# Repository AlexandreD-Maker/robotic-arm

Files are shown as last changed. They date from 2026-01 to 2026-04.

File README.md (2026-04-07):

# Robotic arm project

This repository contains the complete development of my custom robotic arm project, covering mechanical design, embedded control, and system-level integration.

It includes:

- Arduino code
- CAD designs
- Electrical schematic
- [Documentation](docs/index.md) (Github Pages)
---

## Design evolution
This project started as a manually controlled 4-DOF robotic arm using potentiometers, and was progressively extended toward a more structured and testable control architecture.

The evolution focuses on improving motion reproducibility, control clarity, and system testability.

---

## Global architecture

The robotic arm can be controlled using two control modes:
- **Manual mode:** Direct joint control using potentiometers
- **Code-controlled mode:** Joint position commands are sent via the serial interface, allowing reproducible and testable movements. A feedback LED indicates when this mode is active.

The system starts in manual mode by default.

A push button allows safe switching between control modes.

---

## 🚧 Project status

This project is currently under development.

Ongoing work includes:
- CAD design and assembly validation
- creation and expansion of the [technical documentation](docs/index.md).

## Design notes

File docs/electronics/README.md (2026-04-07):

# Electronics

This folder contains the electronic design of the robotic arm, including the schematic, power architecture, and design rationale behind key technical decisions.

---
## System Overview

The electronic system is responsible for:
- Reading user inputs through potentiometers
- Generating PWM signals for servo motor control
- Distributing power safely between logic and actuators
- Ensuring stable electrical references across the system

The architecture separates logic power and actuator power to improve reliability.

---
## Main Components

- **Microcontroller**  
  Arduino UNO R3 board used for:
  - Analog input acquisition
  - PWM signal generation
  - High-level control logic

- **Actuators**
  - 3 × MG996R servo motors (base, shoulder, elbow)
  - 2 × SG90 servo motors (wrist, gripper)

- **User Inputs**
  - Potentiometers connected to analog inputs

- **Power Supply**
  - External 5V / 4A DC supply dedicated to servos
  - USB power for the microcontroller

---
## Power Architecture and Design Rationale

Servo motors are powered by an external 5V supply to avoid voltage drops, noise injection, and brownouts on the microcontroller power rail.

The power supply was dimensioned based on:
- Typical current consumption of each servo during motion
- Realistic operating scenarios where not all servos are simultaneously stalled
- An additional safety margin suitable for a prototype system

This approach provides sufficient current capacity for normal operation while keeping the system simple and easy to scale.

All grounds (external power supply and microcontroller ground) are tied together to ensure correct signal referencing for PWM and analog inputs.

---
## Analog Input Strategy

Potentiometers are powered from the microcontroller 5V rail and connected to analog input pins.

This ensures:
- A stable reference voltage
- Consistent readings independent of servo power fluctuations
- Signal integrity

---
## Schematic

An overview of the circuit diagram is shown below:

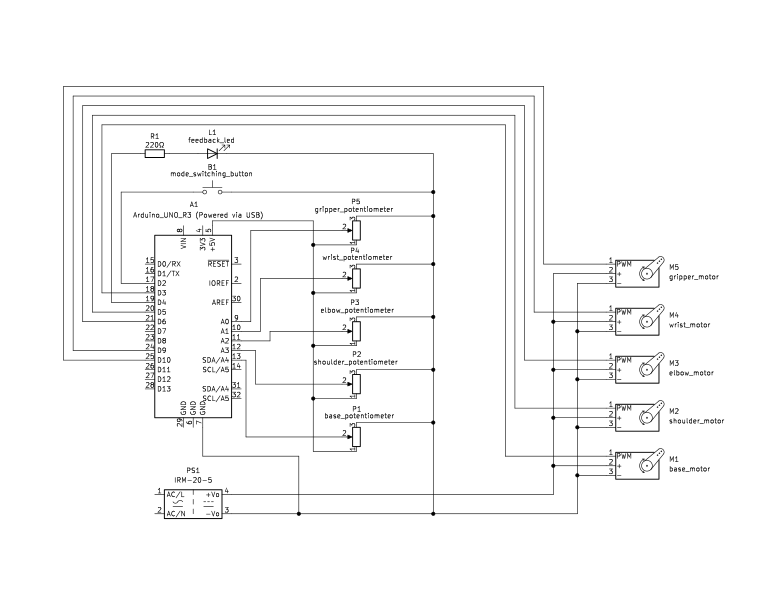
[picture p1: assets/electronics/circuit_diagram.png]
Circuit diagram overview


The complete schematic is also available as a PDF in this directory for detailed inspection.

---
## Tools

- **Schematic design**: KiCad 9.0.6

[Main page](../index.md)

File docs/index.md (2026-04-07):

# Robotic Arm - Technical Documentation

Welcome to the documentation for my custom robotic arm project.

The goal is to design and build a functional and stable robotic arm by using 3D printing, servo motors, potentiometers and an Arduino.
---

## 🎯 Project Goals

- Build a 40 cm robotic arm with clean and stable movements

- Design custom mechanical parts

- Control multiple servos using potentiometers and an Arduino

- Ensure smooth motion without shaking

- Document the project and share all design files
---

## 📂 Repository Structure

- **CAD/** - 3D models (STEP, STL, drawings)
- **electronics/** Circuit diagram
- **firmware/** Control code
- **docs/** Documentation
- **assets/** Images and videos
---

## 🔧 Technologies Used

- **Arduino UNO R3**
- **MG996R / SG90 servos** (depending on the joint)
- **B10K potentiometers** (x5 one for each servos)
- **3D printing** (PLA)
- **Github Pages** for documentation
---

## 📄 Documentation

- **[Electronics](/docs/electronics/README.md)**
- **[Firmware](/firmware/)** (each source file has a doxygen documentation)

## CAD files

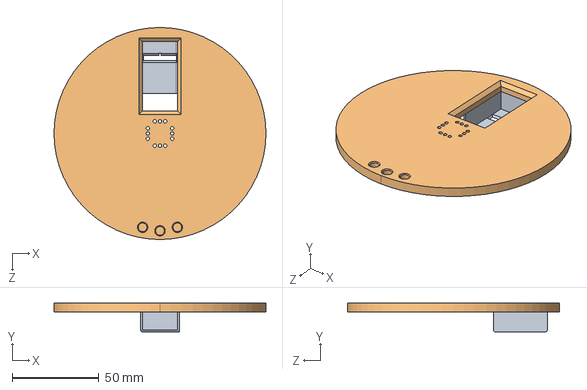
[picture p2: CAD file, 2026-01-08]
CAD/STEP/base_plate.STEP
122.0 x 16.5 x 122.0 mm

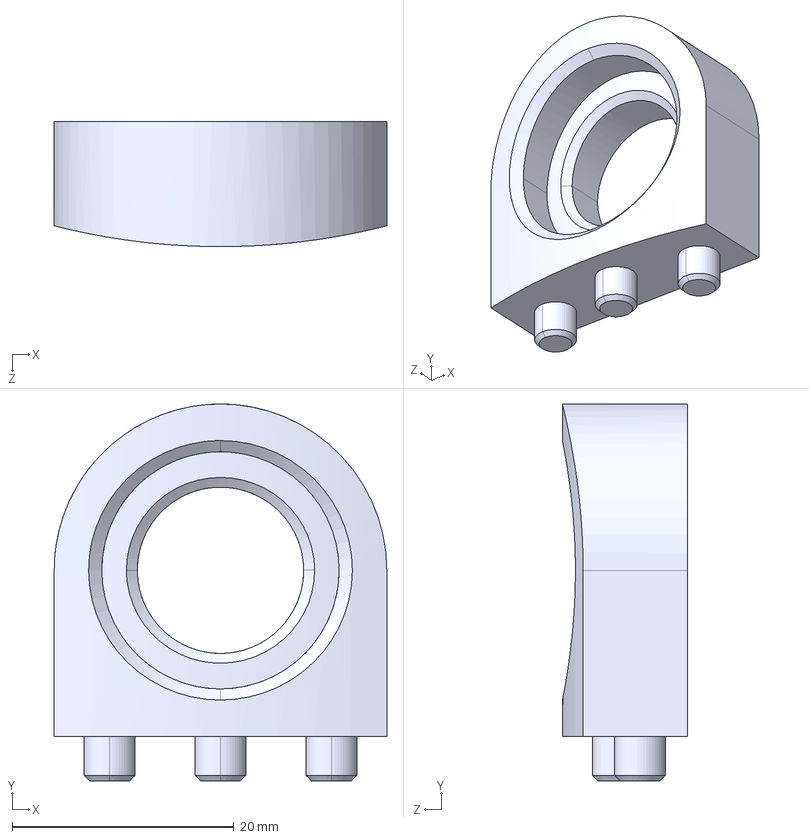
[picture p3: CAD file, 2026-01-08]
CAD/STEP/base_bearing_holder.STEP
30.0 x 34.0 x 11.3 mm

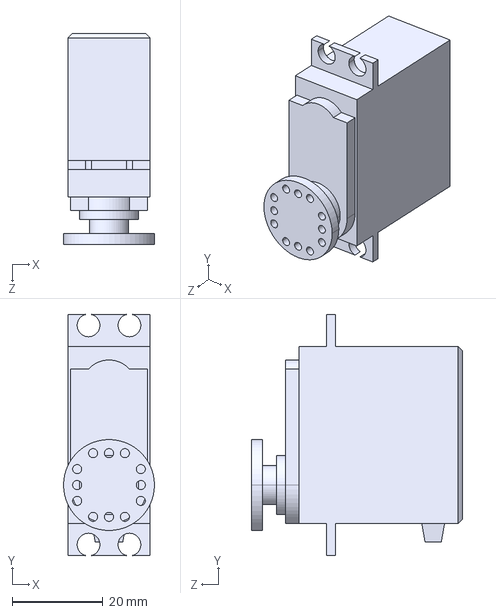
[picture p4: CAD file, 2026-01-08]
CAD/STEP/SG996R_servo_motor.STEP
20.0 x 53.0 x 46.5 mm

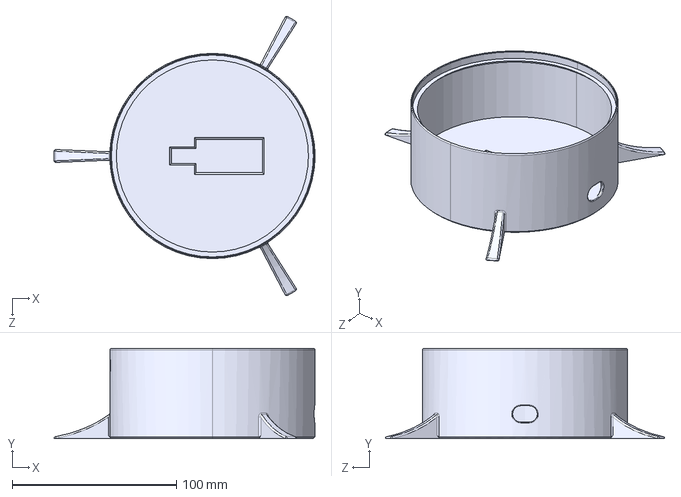
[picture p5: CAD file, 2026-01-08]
CAD/STEP/chassis.STEP
159.0 x 54.9 x 170.3 mm

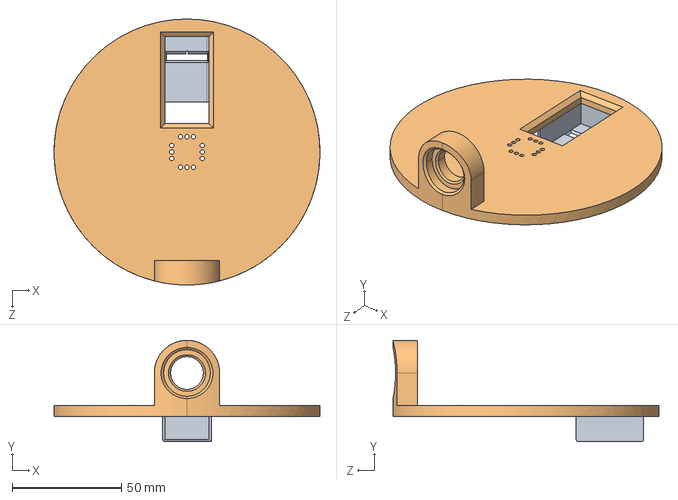
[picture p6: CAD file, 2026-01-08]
CAD/STEP/base.STEP
122.0 x 46.5 x 122.0 mm

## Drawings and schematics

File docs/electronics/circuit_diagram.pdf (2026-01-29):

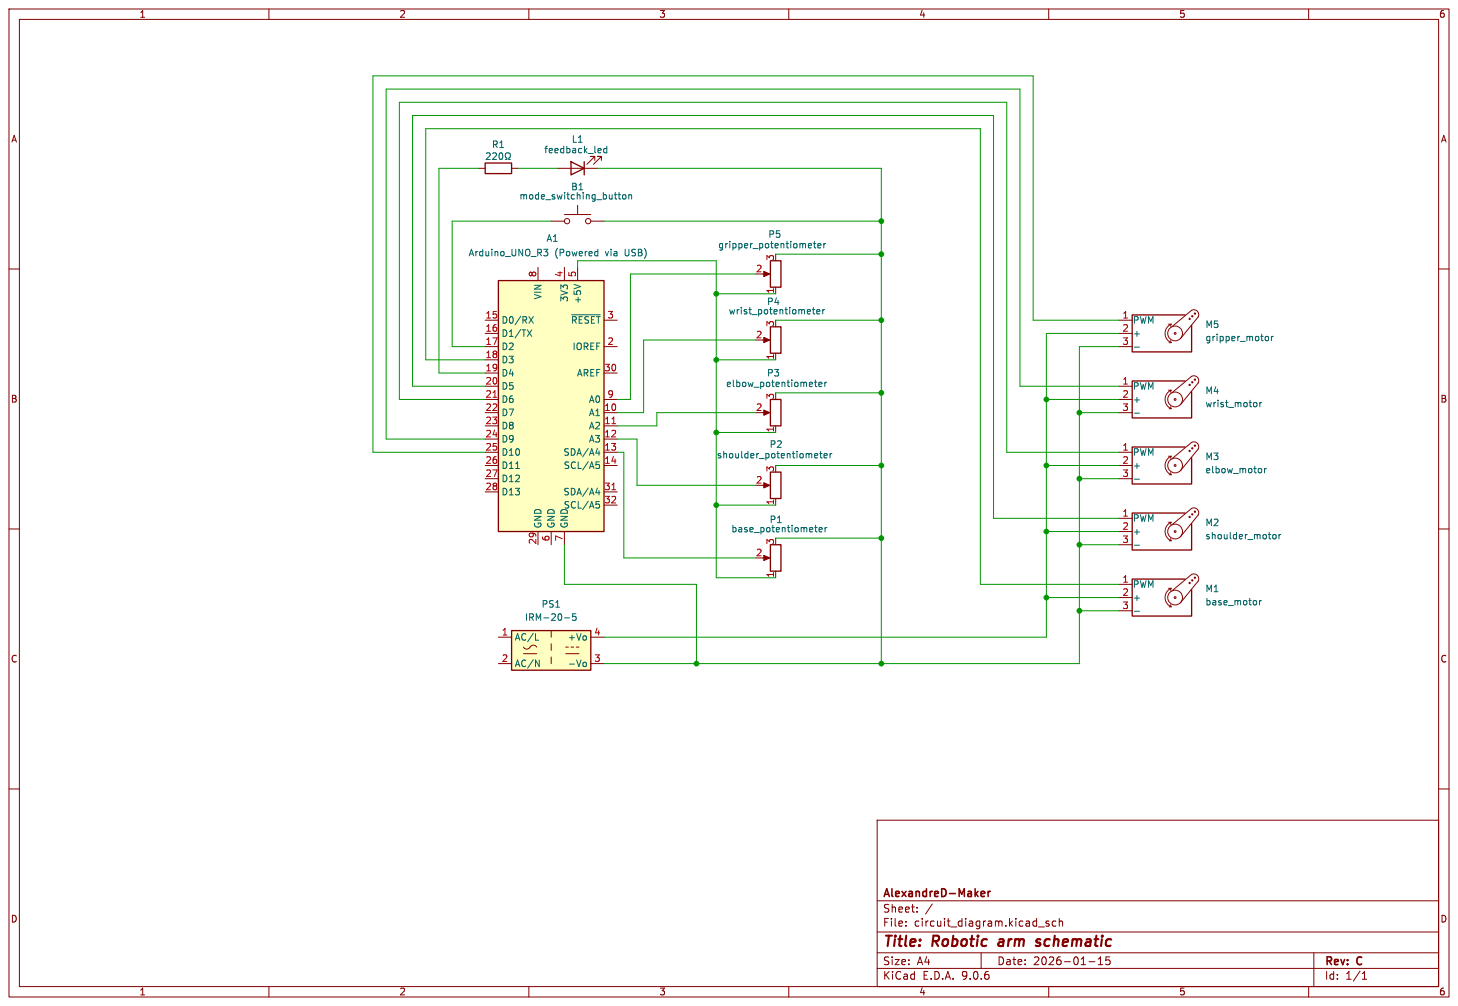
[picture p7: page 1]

File: circuit_diagram.kicad_sch Sheet: / AlexandreD-Maker

Id: 1/1 Title: Robotic arm schematic

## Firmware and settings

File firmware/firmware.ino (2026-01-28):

/**
 * @file firmware.ino
 * @brief Main firmware entry point for the robotic arm
 *
 * This file contains the setup() and loop() functions and acts
 * as the central coordinator of the robotic arm firmware
 *
 * The firmware supports two control modes:
 * - Manual mode: joint angles are controlled using potentiometers
 * - Code-controlled mode: joint angles are received via serial commands
 *
 * A safety mechanism is implemented when switching from code-controlled mode to
 * manual mode to prevent sudden motor movements. Before enabling manual control,
 * potentiometer positions must match the current motor angles within an acceptable tolerance
 *
 * Visual feedback is provided through a status LED:
 * - LED ON: code-controlled mode active
 * - LED BLINKING: potentiometer synchronization required
 * - LED OFF: manual mode active
 *
 */

#include "config.h"
#include "motors.h"
#include "control.h"
#include "mode_switching.h"

void setup() {
    pinMode(FEEDBACK_LED_PIN, OUTPUT);
    // INPUT_PULLUP is set to use the internal resistor of Arduino
    pinMode(MODE_SWITCHING_BUTTON_PIN, INPUT_PULLUP);
    initMotors();
    Serial.begin(9600);
}

void loop() {
        if(mode == MANUAL) {
            readPot();
            for(uint8_t i = 0; i < NUMBER_MOTOR; i++) {
                moveMotor(Joint(i), motorAngle[i]);
            }
        }
        else {
            if(Serial.available() > 0) {
                readUserInput();
            }
            
            for(uint8_t i = 0; i < NUMBER_MOTOR; i++) {
                if(userAngle[i] != -1) {
                    moveMotor(Joint(i), userAngle[i]);
                }
                
            }
        }
        
    if(digitalRead(MODE_SWITCHING_BUTTON_PIN) == 0) {
        delay(250);
        if(mode == CODE_CONTROL) {
            syncPot();
        }
        else {
            for(uint8_t i = 0; i < NUMBER_MOTOR; i++) {
                userAngle[i] = motorAngle[i];
            }
        }
        switchMode();
    }    
    
}

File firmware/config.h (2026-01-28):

/**
 * @file config.h
 * @brief Global configuration and system definitions
 * 
 * This file centralizes all hardware mappings, system-wide constants,
 * and shared enumeration used by the robotic arm firmware
 * 
 */

#pragma once
#include <Arduino.h>

const uint8_t NUMBER_MOTOR = 5;

// Motor pins (PWM capable)
const uint8_t BASE_MOTOR_PIN = 3;
const uint8_t SHOULDER_MOTOR_PIN = 5;
const uint8_t ELBOW_MOTOR_PIN = 6;
const uint8_t WRIST_MOTOR_PIN = 9;
const uint8_t GRIPPER_MOTOR_PIN = 10;

// Potentiometer pins (analog)
const uint8_t BASE_POT_PIN = A0;
const uint8_t SHOULDER_POT_PIN = A1;
const uint8_t ELBOW_POT_PIN = A2;
const uint8_t WRIST_POT_PIN = A3;
const uint8_t GRIPPER_POT_PIN = A4;

// Mode switching pins
const uint8_t FEEDBACK_LED_PIN = 2;
const uint8_t MODE_SWITCHING_BUTTON_PIN = 4;

// Joint indices
enum Joint {
    BASE = 0,
    SHOULDER,
    ELBOW,
    WRIST,
    GRIPPER
};

// Control mode indices
enum ControlMode {
    MANUAL = 0,
    CODE_CONTROL
};

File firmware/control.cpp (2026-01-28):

#include "control.h"
#include "mode_switching.h"

uint8_t motorAngle[NUMBER_MOTOR];
String userInput[NUMBER_MOTOR];

uint8_t potPin[NUMBER_MOTOR] = {
    BASE_POT_PIN,
    SHOULDER_POT_PIN,
    ELBOW_POT_PIN,
    WRIST_POT_PIN,
    GRIPPER_POT_PIN
};

void readPot() {
    for(uint8_t i = 0; i < NUMBER_MOTOR; i++) {
        motorAngle[i] = map(analogRead(potPin[i]), 0, 1023, 0, 180);
    }
}

void readUserInput() {

    // Set all element of userInput to empty string
    for(uint8_t i = 0; i < NUMBER_MOTOR; i++) {
      userInput[i] = "";
    }

    // Getting user input and parsing it
    String received_data = Serial.readStringUntil("\n");
    received_data.trim();

    uint8_t word_counter = 0;
    // Ensure user input is 5 arguments max
    if(word_counter < NUMBER_MOTOR) { 
        for(char c : received_data) {
        
            if(!isSpace(c)) {
              userInput[word_counter] += c;
            }

            else {
                word_counter++;
            }
        }
    }
    for(uint8_t i = 0; i < NUMBER_MOTOR; i++) {
        // If user entered "-" or no value, the current angle doesn't change
        if(userInput[i] == "-" || userInput[i] == "") { 
            userAngle[i] = userAngle[i];
        }
        // Ensure the angle is between 0 and 180°
        else if(userInput[i].toInt() <= 180 && readUserInput[i] >= 0) {
            userAngle[i] = userInput[i].toInt();
        }
    }
    
}

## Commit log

2025-12-20 added circuit diagram
    [circuit_diagram.kicad_sch]
2026-01-05 added manual motors control with potentiometers
2026-01-06 added chassis STEP file
    [chassis.STEP]
2026-01-08 updated README and added STEP files: - chassis - base (separated in 2 files for printing) - SG996R servo motor
    [SG996R_servo_motor.STEP, base.STEP, base_bearing_holder.STEP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]
2026-01-09 added mode switching button and feedback LED
    [circuit_diagram.kicad_sch]
2026-01-15 fixed potentiometer supply: use Arduino 5V instead of external power
    [circuit_diagram.kicad_sch]
2026-01-28 implemented safe mode switching with visual feedback
    - added code-controlled mode
    - implemented potentiometer synchronisation when returning to manual mode
    - added LED feedback to indicate system state
